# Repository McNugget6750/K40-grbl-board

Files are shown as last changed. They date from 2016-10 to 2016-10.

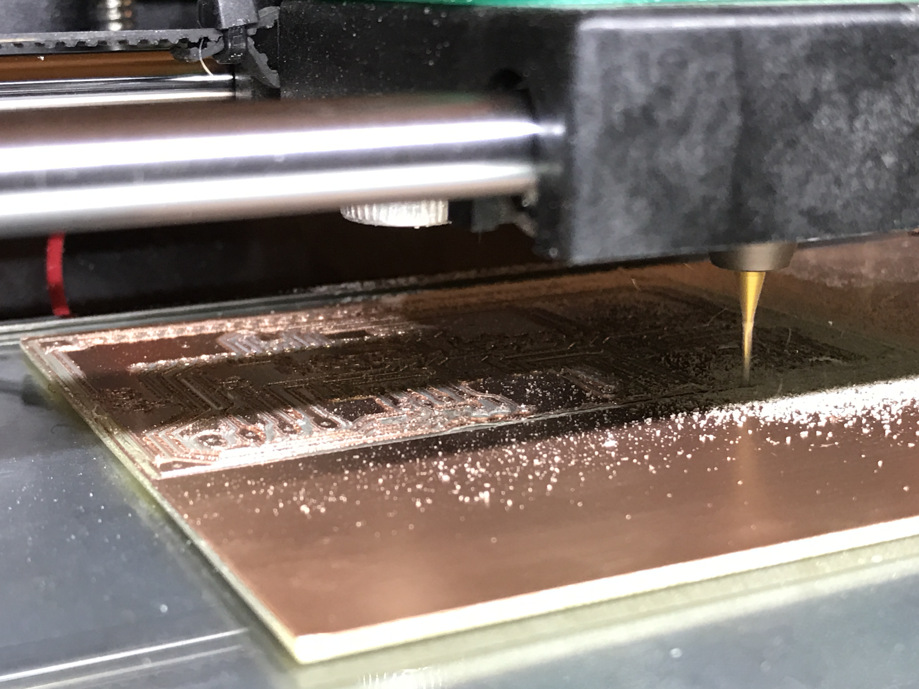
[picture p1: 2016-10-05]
pictures/IMG_8589.JPG

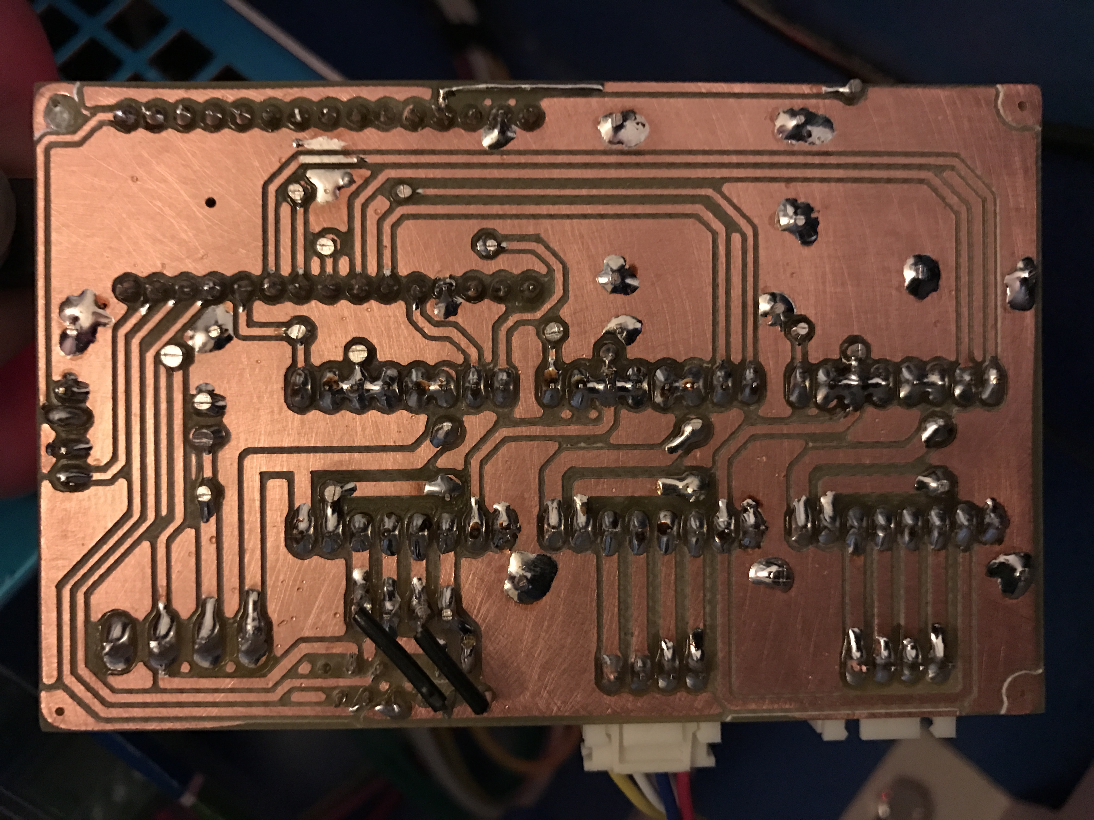
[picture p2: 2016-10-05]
pictures/IMG_8592.JPG

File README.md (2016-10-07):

_**K40-grbl-board**_

A PCB layout and schematic.

Made with Eagle PCB 7.4.0 Light

This board comes from here: https://github.com/McNugget6750/K40-grbl-board
Author: Timo Birnschein (timo.birnschein at microforge.de)
Please consider giving credit where credit is due.
Please check for updates in the future.

Based on schematics from https://github.com/txjammer (seems offline)

_**DISCLAMER!**_

USE AT YOU OWN RISK!
I CANNOT BE MADE RESPONSIBLE FOR ANY PROBLEMS THAT MIGHT OCCUR WHILE USING THIS.
THIS IS A HOBBY DEVELOPMENT AND NO TESTING HAS BEEN DONE TO ENSURE THE SAVETY OF ANY
OF YOUR EQUIPMENT OR YOUR HOUSE, YOUR LIFE OR ANYTHING ELSE! DO NOT USE UNLESS YOU UNDERSTAND
THIS! WORKING WITH LASERS AND HIGH VOLTAGE POWER SUPPLIES IS DANGEROUS AND SHOULD
ONLY BE DONE BY EXPERIENCED PEOPLE! NEVER USE WITHOUT LINE OF SIGHT TO THE MACHINE!!
YOUR LASER WILL EVENTUALLY BE ON FIRE! IT HAPPENED TO EVERYONE OF US BEFORE!
ALWAYS BE CAUTIOUS! ALWAYS WATCH YOUR MACHINE WHILE OPERATING IT!

_**Requirements**_

* an arduino nano w atmega328p loaded with grbl http://github.com/grbl/grbl
* 2 Pololu A4988 Stepper motor drivers with current limit set to ~1A (Vref=0.4V)
* a ribbon connector from the original moshi board or this one: http://www.digikey.com/product-search/en?keywords=A100331-ND
* a four pole power connector: MTA04-156 with this package: 1X4MTA
* 4x1 pin header or one of the original moshi stepper motor driver connectors
* grbl form from here: https://github.com/McNugget6750/grbl

_**Software to control the GRBL Laser for cutting**_

I'm using dxf2gcode (with the configurations and source files included in this repository): https://sourceforge.net/projects/dxf2gcode

I also use GRBL-Controller (with the grbl configuration file included in this repository): http://zapmaker.org/projects/grbl-controller-3-0/

My grbl works with relative coordinates. Please keep that in mind.

_**GRBL Config Modifications**_
Modifications for config.h are required!

Modify homing cycle:
- #define HOMING_CYCLE_0 (1<<X_AXIS)
- #define HOMING_CYCLE_1 (1<<Y_AXIS)

Invert spindle enable pin by enabling:
- #define INVERT_SPINDLE_ENABLE_PIN // Default disabled. Uncomment to enable.

Enable variable spindle speed if not done by default. This gives you hardware PWM on Pin D11.
- #define VARIABLE_SPINDLE // Default enabled. Comment to disable.

Remap spindle enable pin to pin D13 by enabling (WARNING! WILL BE PULLED LOW BY BOOT LOADER DURING POWER UP! DEACTIVATE YOUR LASER DURING STARTUP OF BOARD IN ORDER TO PREVENT FULL POWER BURNS AT STARTUP.):
- #define USE_SPINDLE_DIR_AS_ENABLE_PIN // Default disabled. Uncomment to enable.

In file spindle_control.c I changed the PWM prescaler for the laser to make it more precise and easier to control by changing line 94 from
- TCCRB_REGISTER = (TCCRB_REGISTER & 0b11111000) | 0x02; // set to 1/8 Prescaler
to
- TCCRB_REGISTER = (TCCRB_REGISTER & 0b11111000) | 0x01; // set to No Prescaling

_**GRBL Configuration that currently sort of works**_
```
$0=10 (step pulse, usec)
$1=25 (step idle delay, msec)
$2=0 (step port invert mask:00000000)
$3=1 (dir port invert mask:00000001)
$4=0 (step enable invert, bool)
$5=1 (limit pins invert, bool)
$6=0 (probe pin invert, bool)
$10=3 (status report mask:00000011)
$11=0.010 (junction deviation, mm)
$12=0.002 (arc tolerance, mm)
$13=0 (report inches, bool)
$20=0 (soft limits, bool)
$21=0 (hard limits, bool)
$22=1 (homing cycle, bool)
$23=3 (homing dir invert mask:00000011)
$24=200.000 (homing feed, mm/min)
$25=8000.000 (homing seek, mm/min)
$26=250 (homing debounce, msec)
$27=1.000 (homing pull-off, mm)
$100=157.575 (x, step/mm)
$101=157.575 (y, step/mm)
$102=250.000 (z, step/mm)
$110=12000.000 (x max rate, mm/min)
$111=12000.000 (y max rate, mm/min)
$112=12000.000 (z max rate, mm/min)
$120=4000.000 (x accel, mm/sec^2)
$121=4000.000 (y accel, mm/sec^2)
$122=1000.000 (z accel, mm/sec^2)
$130=200.000 (x max travel, mm)
$131=300.000 (y max travel, mm)
$132=10.000 (z max travel, mm)
```

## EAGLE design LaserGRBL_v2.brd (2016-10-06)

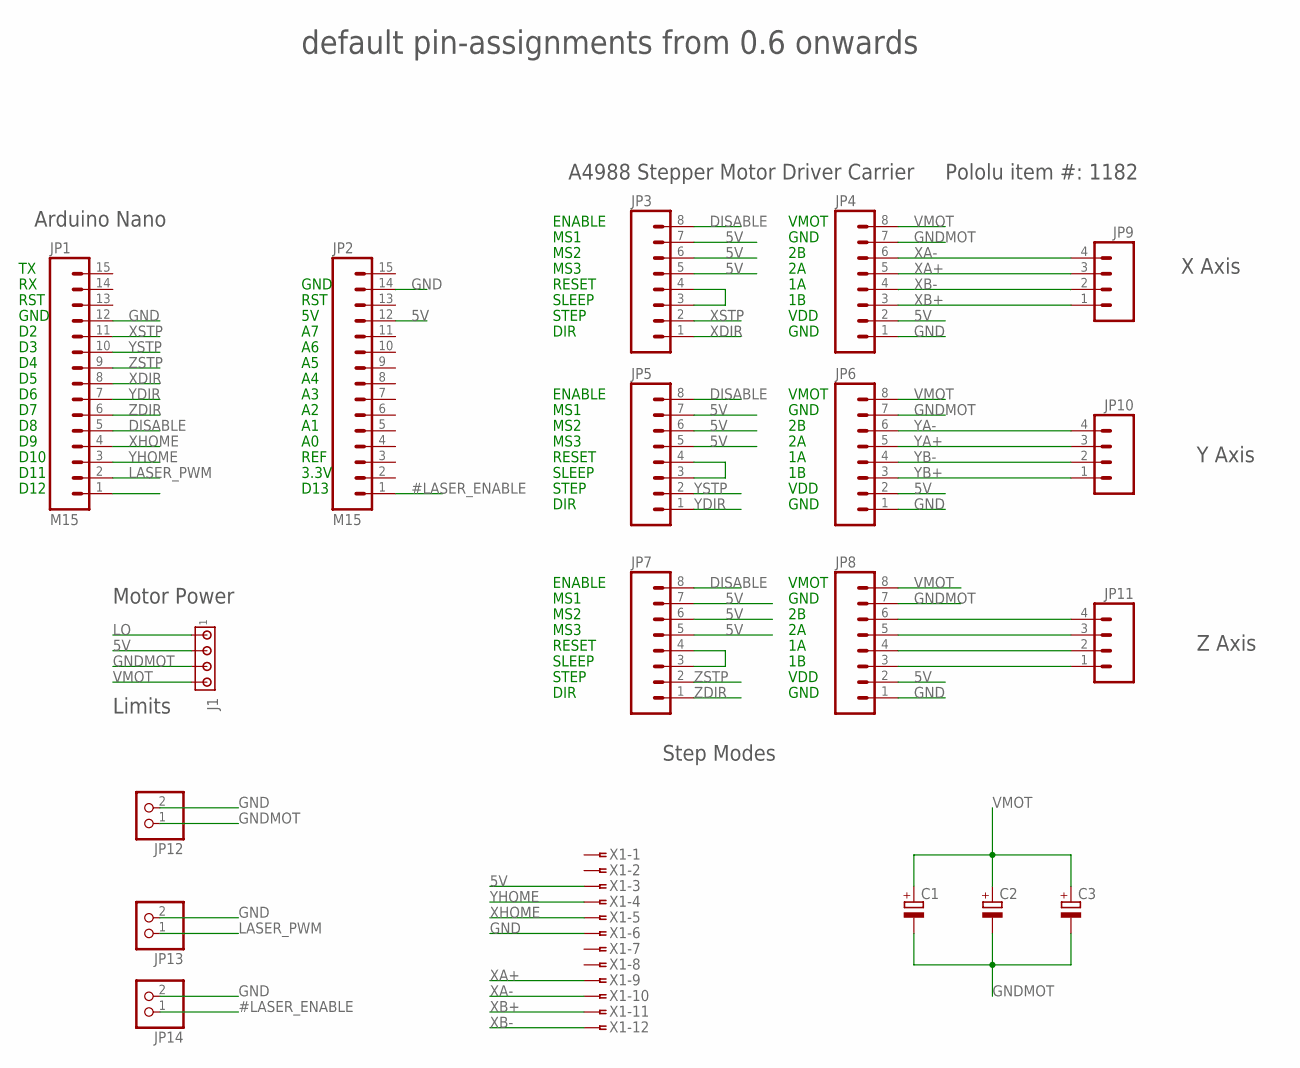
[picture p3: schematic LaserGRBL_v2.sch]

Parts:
C1, C2, C3: CPOL-EUE5-10.5; E5-10,5
J1: MTA04-156; 1X4MTA
JP1, JP2: M15; 1X15
JP3, JP4, JP5, JP6, JP7, JP8: M08LONGPADS; 1X08_LONGPADS
JP9, JP10, JP11: M04LONGPADS; 1X04_LONGPADS
JP12, JP13, JP14: PINHD-1X2; 1X02
X1: FSIDE-12

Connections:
5V: J1.2, JP2.12, JP3.5, JP3.6, JP3.7, JP4.2, JP5.5, JP5.6, JP5.7, JP6.2, JP7.5, JP7.6, JP7.7, JP8.2, X1.3
#LASER_ENABLE: JP2.1, JP14.1
DISABLE: JP1.5, JP3.8, JP5.8, JP7.8
GND: JP1.12, JP2.14, JP4.1, JP6.1, JP8.1, JP12.2, JP13.2, JP14.2, X1.6
GNDMOT: C1.-, C2.-, C3.-, J1.3, JP4.7, JP6.7, JP8.7, JP12.1
LASER_PWM: JP1.2, JP13.1
LO: J1.1
unnamed: JP5.3, JP5.4
unnamed: JP8.6, JP11.4
unnamed: JP8.5, JP11.3
unnamed: JP8.4, JP11.2
unnamed: JP8.3, JP11.1
unnamed: JP7.3, JP7.4
unnamed: JP3.3, JP3.4
VMOT: C1.+, C2.+, C3.+, J1.4, JP4.8, JP6.8, JP8.8
XA+: JP4.5, JP9.3, X1.9
XA-: JP4.6, JP9.4, X1.10
XB+: JP4.3, JP9.1, X1.11
XB-: JP4.4, JP9.2, X1.12
XDIR: JP1.8, JP3.1
XHOME: JP1.4, X1.5
XSTP: JP1.11, JP3.2
YA+: JP6.5, JP10.3
YA-: JP6.6, JP10.4
YB+: JP6.3, JP10.1
YB-: JP6.4, JP10.2
YDIR: JP1.7, JP5.1
YHOME: JP1.3, X1.4
YSTP: JP1.10, JP5.2
ZDIR: JP1.6, JP7.1
ZSTP: JP1.9, JP7.2

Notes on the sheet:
D10
GND
D11
D12
DIR
STEP
SLEEP
MS3
MS2
MS1
ENABLE
RESET
VDD
VMOT
default pin-assignments from 0.6 onwards
Step Modes
Arduino Nano
A4988 Stepper Motor Driver Carrier
Pololu item #: 1182
Motor Power
RST
REF
3.3V
D13
Limits
X Axis
Y Axis
Z Axis

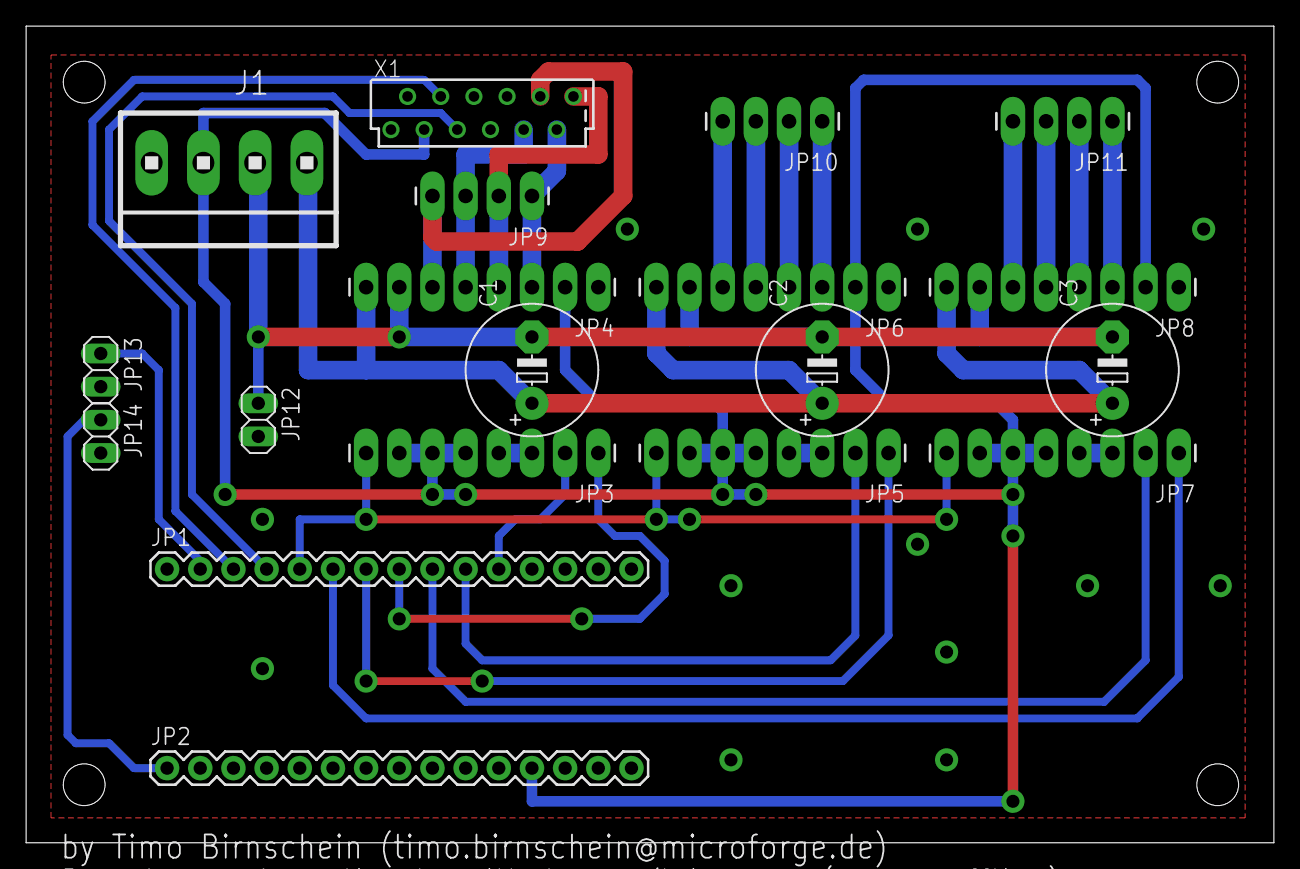
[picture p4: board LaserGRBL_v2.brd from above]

Board: 2 copper layers, 95.5 x 62.5 mm, 19 parts (0 on the bottom side), 30 nets.

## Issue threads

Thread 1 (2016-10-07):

No Make File in Grbl Directory

nickw89509, 2016-10-07:
Just compiled your code had to copy the make file into the grbl directory

McNugget6750, 2016-10-07:
You're right... It's because I use the Arduino uploader to compile and upload the code as provided by grbl master...

McNugget6750, 2016-10-07:
Please check this out, now it's all there: https://github.com/McNugget6750/grbl

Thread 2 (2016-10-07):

BOM for parts

nickw89509, 2016-10-07:
It would be nice to provide a bill of material for the board

McNugget6750, 2016-10-07:
Should be available in readme.

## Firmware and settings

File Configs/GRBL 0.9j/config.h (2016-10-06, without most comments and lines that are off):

#define config_h
#include "grbl.h" // For Arduino IDE compatibility.
#define DEFAULTS_GENERIC
#define BAUD_RATE 115200
#define CPU_MAP_ATMEGA328P // Arduino Uno CPU
#define CMD_STATUS_REPORT '?'
#define CMD_FEED_HOLD '!'
#define CMD_CYCLE_START '~'
#define CMD_RESET 0x18 // ctrl-x.
#define CMD_SAFETY_DOOR '@'
#define HOMING_CYCLE_0 (1<<X_AXIS)
#define HOMING_CYCLE_1 (1<<Y_AXIS)
#define N_HOMING_LOCATE_CYCLE 1 // Integer (1-128)
#define N_STARTUP_LINE 2 // Integer (1-2)
#define N_DECIMAL_COORDVALUE_INCH 4 // Coordinate or position value in inches
#define N_DECIMAL_COORDVALUE_MM   3 // Coordinate or position value in mm
#define N_DECIMAL_RATEVALUE_INCH  1 // Rate or velocity value in in/min
#define N_DECIMAL_RATEVALUE_MM    0 // Rate or velocity value in mm/min
#define N_DECIMAL_SETTINGVALUE    3 // Decimals for floating point setting values
#define MESSAGE_PROBE_COORDINATES // Enabled by default. Comment to disable.
#define SAFETY_DOOR_SPINDLE_DELAY 0
#define SAFETY_DOOR_COOLANT_DELAY 0
#define INVERT_SPINDLE_ENABLE_PIN // Default disabled. Uncomment to enable.
#define ACCELERATION_TICKS_PER_SECOND 100
#define ADAPTIVE_MULTI_AXIS_STEP_SMOOTHING  // Default enabled. Comment to disable.
#define TOOL_LENGTH_OFFSET_AXIS Z_AXIS // Default z-axis. Valid values are X_AXIS, Y_AXIS, or Z_AXIS.
#define VARIABLE_SPINDLE // Default enabled. Comment to disable.
#define SPINDLE_MAX_RPM 1000.0 // Max spindle RPM. This value is equal to 100% duty cycle on the PWM.
#define SPINDLE_MIN_RPM 0.0    // Min spindle RPM. This value is equal to (1/256) duty cycle on the PWM.
#define USE_SPINDLE_DIR_AS_ENABLE_PIN // Default disabled. Uncomment to enable.
#define MINIMUM_JUNCTION_SPEED 0.0 // (mm/min)
#define MINIMUM_FEED_RATE 1.0 // (mm/min)
#define N_ARC_CORRECTION 12 // Integer (1-255)
#define ARC_ANGULAR_TRAVEL_EPSILON 5E-7 // Float (radians)
#define DWELL_TIME_STEP 50 // Integer (1-255) (milliseconds)
#if defined(USE_SPINDLE_DIR_AS_ENABLE_PIN) && !defined(VARIABLE_SPINDLE)
  #error "USE_SPINDLE_DIR_AS_ENABLE_PIN may only be used with VARIABLE_SPINDLE enabled"
#endif
#if defined(USE_SPINDLE_DIR_AS_ENABLE_PIN) && !defined(CPU_MAP_ATMEGA328P)
  #error "USE_SPINDLE_DIR_AS_ENABLE_PIN may only be used with a 328p processor"
#endif

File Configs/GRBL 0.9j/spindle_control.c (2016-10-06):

/*
  spindle_control.c - spindle control methods
  Part of Grbl

  Copyright (c) 2012-2015 Sungeun K. Jeon
  Copyright (c) 2009-2011 Simen Svale Skogsrud

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
  You should have received a copy of the GNU General Public License
  along with Grbl.  If not, see <http://www.gnu.org/licenses/>.
*/

#include "grbl.h"


void spindle_init()
{
  // Configure variable spindle PWM and enable pin, if requried. On the Uno, PWM and enable are
  // combined unless configured otherwise.
  #ifdef VARIABLE_SPINDLE
    SPINDLE_PWM_DDR |= (1<<SPINDLE_PWM_BIT); // Configure as PWM output pin.
    #if defined(CPU_MAP_ATMEGA2560) || defined(USE_SPINDLE_DIR_AS_ENABLE_PIN)
      SPINDLE_ENABLE_DDR |= (1<<SPINDLE_ENABLE_BIT); // Configure as output pin.
    #endif
  // Configure no variable spindle and only enable pin.
  #else
    SPINDLE_ENABLE_DDR |= (1<<SPINDLE_ENABLE_BIT); // Configure as output pin.
  #endif

  #ifndef USE_SPINDLE_DIR_AS_ENABLE_PIN
    SPINDLE_DIRECTION_DDR |= (1<<SPINDLE_DIRECTION_BIT); // Configure as output pin.
  #endif
  spindle_stop();
}


void spindle_stop()
{
  // On the Uno, spindle enable and PWM are shared. Other CPUs have seperate enable pin.
  #ifdef VARIABLE_SPINDLE
    TCCRA_REGISTER &= ~(1<<COMB_BIT); // Disable PWM. Output voltage is zero.
    #if defined(CPU_MAP_ATMEGA2560) || defined(USE_SPINDLE_DIR_AS_ENABLE_PIN)
      #ifdef INVERT_SPINDLE_ENABLE_PIN
        SPINDLE_ENABLE_PORT |= (1<<SPINDLE_ENABLE_BIT);  // Set pin to high
      #else
        SPINDLE_ENABLE_PORT &= ~(1<<SPINDLE_ENABLE_BIT); // Set pin to low
      #endif
    #endif
  #else
    #ifdef INVERT_SPINDLE_ENABLE_PIN
      SPINDLE_ENABLE_PORT |= (1<<SPINDLE_ENABLE_BIT);  // Set pin to high
    #else
      SPINDLE_ENABLE_PORT &= ~(1<<SPINDLE_ENABLE_BIT); // Set pin to low
    #endif
  #endif
}


void spindle_set_state(uint8_t state, float rpm)
{
  // Halt or set spindle direction and rpm.
  if (state == SPINDLE_DISABLE) {

    spindle_stop();

  } else {

    #ifndef USE_SPINDLE_DIR_AS_ENABLE_PIN
      if (state == SPINDLE_ENABLE_CW) {
        SPINDLE_DIRECTION_PORT &= ~(1<<SPINDLE_DIRECTION_BIT);
      } else {
        SPINDLE_DIRECTION_PORT |= (1<<SPINDLE_DIRECTION_BIT);
      }
    #endif

    #ifdef VARIABLE_SPINDLE
      // TODO: Install the optional capability for frequency-based output for servos.
      #ifdef CPU_MAP_ATMEGA2560
      	TCCRA_REGISTER = (1<<COMB_BIT) | (1<<WAVE1_REGISTER) | (1<<WAVE0_REGISTER);
        TCCRB_REGISTER = (TCCRB_REGISTER & 0b11111000) | 0x02 | (1<<WAVE2_REGISTER) | (1<<WAVE3_REGISTER); // set to 1/8 Prescaler
        OCR4A = 0xFFFF; // set the top 16bit value
        uint16_t current_pwm;
      #else
        TCCRA_REGISTER = (1<<COMB_BIT) | (1<<WAVE1_REGISTER) | (1<<WAVE0_REGISTER);
        //TCCRB_REGISTER = (TCCRB_REGISTER & 0b11111000) | 0x02; // set to 1/8 Prescaler
        TCCRB_REGISTER = (TCCRB_REGISTER & 0b11111000) | 0x01; // set to No Prescaling
        uint8_t current_pwm;
      #endif

      if (rpm <= 0.0) { spindle_stop(); } // RPM should never be negative, but check anyway.
      else {
        #define SPINDLE_RPM_RANGE (SPINDLE_MAX_RPM-SPINDLE_MIN_RPM)
        if ( rpm < SPINDLE_MIN_RPM ) { rpm = 0; }
        else {
          rpm -= SPINDLE_MIN_RPM;
          if ( rpm > SPINDLE_RPM_RANGE ) { rpm = SPINDLE_RPM_RANGE; } // Prevent integer overflow
        }
        current_pwm = floor( rpm*(PWM_MAX_VALUE/SPINDLE_RPM_RANGE) + 0.5);
        #ifdef MINIMUM_SPINDLE_PWM
          if (current_pwm < MINIMUM_SPINDLE_PWM) { current_pwm = MINIMUM_SPINDLE_PWM; }
        #endif

        #ifdef INVERT_SPINDLE_PWM
        	OCR_REGISTER = PWM_MAX_VALUE - current_pwm; // Set the invert PWM pin output
        #else
        	OCR_REGISTER = current_pwm; // Set PWM pin output
		#endif

        // On the Uno, spindle enable and PWM are shared, unless otherwise specified.
        #if defined(CPU_MAP_ATMEGA2560) || defined(USE_SPINDLE_DIR_AS_ENABLE_PIN)
          #ifdef INVERT_SPINDLE_ENABLE_PIN
            SPINDLE_ENABLE_PORT &= ~(1<<SPINDLE_ENABLE_BIT);	// Set pin to low
          #else
            SPINDLE_ENABLE_PORT |= (1<<SPINDLE_ENABLE_BIT);		// Set pin to high
          #endif
        #endif
      }

    #else
      // NOTE: Without variable spindle, the enable bit should just turn on or off, regardless
      // if the spindle speed value is zero, as its ignored anyhow.
      #ifdef INVERT_SPINDLE_ENABLE_PIN
        SPINDLE_ENABLE_PORT &= ~(1<<SPINDLE_ENABLE_BIT);
      #else
        SPINDLE_ENABLE_PORT |= (1<<SPINDLE_ENABLE_BIT);
      #endif
    #endif

  }
}


void spindle_run(uint8_t state, float rpm)
{
  if (sys.state == STATE_CHECK_MODE) { return; }
  protocol_buffer_synchronize(); // Empty planner buffer to ensure spindle is set when programmed.
  spindle_set_state(state, rpm);
}

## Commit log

2016-10-05 Version 0.1 of the K40 grbl compatible board.
    [LaserGRBL_v2.brd, LaserGRBL_v2.sch]
2016-10-06 Some changes to the board file to make it manufacturable.
    [LaserGRBL_v2.brd]
2016-10-06 Adding a couple of configs and grbl source files that I modified.
    [K40LaserConfig.cfg, config.cfg, config.h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]
2016-10-07 Adding my current working grbl 0.9j firmware with ported realtime extensions for planned variable laser power from Nick Williams grbl repository. One last thing I don't understand yet: After homing a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
    [config.h, cpu_map.h, defaults.h]
2016-10-07 just a non empty commit
    [config.h]
2016-10-07 updated grbl config
    [grbl-0.9j configuration.txt]
2016-10-07 removed grbl from this repository. Now here: https://github.com/McNugget6750/grbl
    [config.h, cpu_map.h, defaults.h]
2016-10-07 changed config to absolute since it is now working fine
    [K40LaserConfig.cfg]

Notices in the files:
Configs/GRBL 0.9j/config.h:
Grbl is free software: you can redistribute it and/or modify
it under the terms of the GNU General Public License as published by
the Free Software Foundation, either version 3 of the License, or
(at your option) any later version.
